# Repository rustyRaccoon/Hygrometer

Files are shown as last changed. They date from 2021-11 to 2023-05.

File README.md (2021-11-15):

# Hygrometer
Hygrometer based on DHT11 and four 7-segment displays

DHT library took way too much space so I had to code the communication directly.
As of v4.0 this works quite nicely.

I got the power consumption down to 0.1 mA/h:
<1 mA in sleep mode (my lab power supply doesn't show any current draw)
~6 mA when updating measurements (currently 2 measurements aka 8 seconds every 5 minutes)
~68 mA when displaying measurements (currently for 5 seconds)

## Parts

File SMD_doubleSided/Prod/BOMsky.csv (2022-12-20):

Id | Designator | Package | Quantity | Designation | Supplier and ref
1 | R2,R3,R5,R6,R7,R8,R9,R10,R11,R12,R13,R14,R15,R16,R17,R4 | R_1206_3216Metric_Pad1.30x1.75mm_HandSolder | 16 | 270
2 | U2,U3 | SOIC-16_3.9x9.9mm_P1.27mm | 2 | 74HC595
3 | J1 | PinHeader_1x02_P2.54mm_Vertical | 1 | POWER
4 | R1,R19,R18,R20 | R_1206_3216Metric_Pad1.30x1.75mm_HandSolder | 4 | 10k
5 | SW1 | PinHeader_1x02_P2.54mm_Vertical | 1 | WAKE UP
6 | J6 | PinHeader_1x04_P2.54mm_Vertical | 1 | DHT11
7 | Q1,Q2 | SOT-23_Handsoldering | 2 | NPN_CBE
8 | C4 | CP_EIA-3216-18_Kemet-A_Pad1.58x1.35mm_HandSolder | 1 | 4.7u
9 | C2,C3,C1 | CP_EIA-3216-18_Kemet-A_Pad1.58x1.35mm_HandSolder | 3 | 100n
10 | U1 | FakeSMD_DIP-8 | 1 | ATtiny45V-10P
11 | U4,U5 | HDSP-523Y | 2 | HDSP-523Y

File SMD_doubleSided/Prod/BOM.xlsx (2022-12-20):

Designator | Package | Quantity | Designation | Sourced | Order number
R2,R3,R5,R6,R7,R8,R9,R10,R11,R12,R13,R14,R15,R16,R17,R4 | R_1206_3216Metric_Pad1.30x1.75mm_HandSolder | 16 | R270 | YES | NA
U2,U3 | SOIC-16_3.9x9.9mm_P1.27mm | 2 | 74HC595 | YES | NA
J1 | PinHeader_1x02_P2.54mm_Vertical | 1 | POWER | YES | NA
R1,R19,R18,R20 | R_1206_3216Metric_Pad1.30x1.75mm_HandSolder | 4 | 10k | YES | NA
SW1 | PinHeader_1x02_P2.54mm_Vertical | 1 | WAKE UP | YES | NA
J6 | PinHeader_1x04_P2.54mm_Vertical | 1 | DHT11 | YES | NA
Q1,Q2 | SOT-23_Handsoldering | 2 | NPN_CBE | YES | NA
C4 | CP_EIA-3216-18_Kemet-A_Pad1.58x1.35mm_HandSolder | 1 | 4.7u | YES | NA
C2,C3,C1 | CP_EIA-3216-18_Kemet-A_Pad1.58x1.35mm_HandSolder | 3 | 100n | YES | NA
U1 | FakeSMD_DIP-8 | 1 | ATtiny45V-10P | YES | NA
U4,U5 | HDSP-523Y | 2 | HDSP-523Y | YES | NA

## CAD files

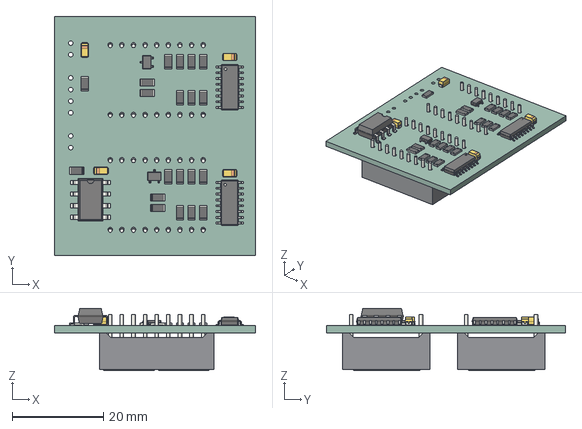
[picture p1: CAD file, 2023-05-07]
SMD_doubleSided/Hygrometer_SMD_doubleSided.step
43.9 x 52.3 x 13.6 mm
PCB

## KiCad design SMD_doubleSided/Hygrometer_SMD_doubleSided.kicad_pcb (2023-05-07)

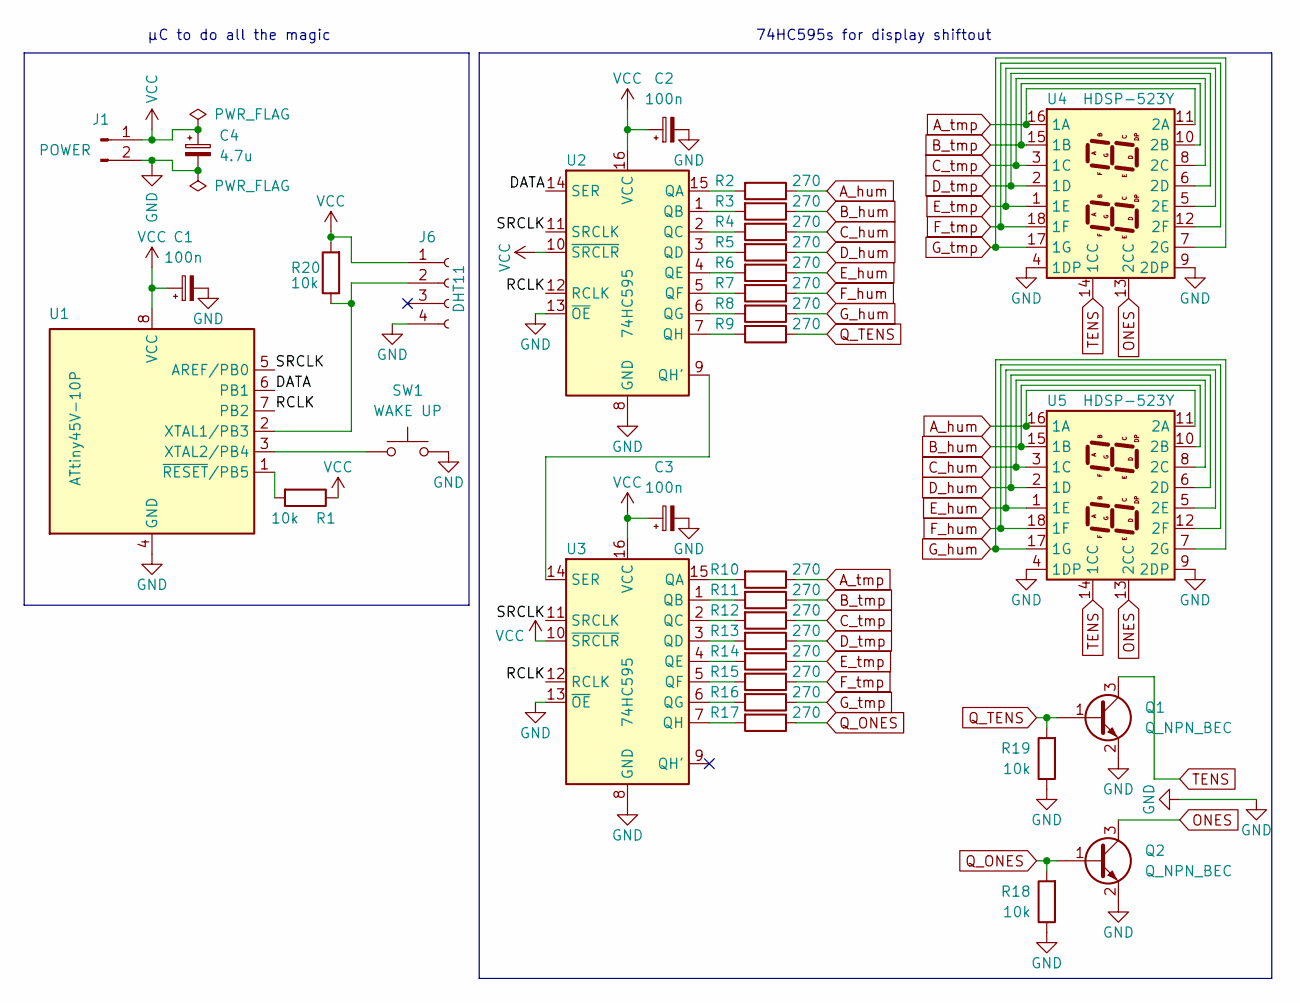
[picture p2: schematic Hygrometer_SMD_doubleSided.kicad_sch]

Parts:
C1, C2, C3: 100n; CP_EIA-3216-18_Kemet-A_Pad1.58x1.35mm_HandSolder
C4: 4.7u; CP_EIA-3216-18_Kemet-A_Pad1.58x1.35mm_HandSolder
J1: POWER; PinHeader_1x02_P2.54mm_Vertical
J6: DHT11; PinHeader_1x04_P2.54mm_Vertical
Q1, Q2: Q_NPN_BEC; SOT-23W
R1, R18, R19, R20: 10k; R_1206_3216Metric_Pad1.30x1.75mm_HandSolder
R2, R3, R4, R5, R6, R7, R8, R9, R10, R11, R12, R13, R14, R15, R16, R17: 270; R_1206_3216Metric_Pad1.30x1.75mm_HandSolder
SW1: WAKE UP; PinHeader_1x02_P2.54mm_Vertical
U1: ATtiny45V-10P; FakeSMD_DIP-8
U2, U3: 74HC595; SOIC-16_3.9x9.9mm_P1.27mm
U4, U5: HDSP-523Y

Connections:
/DATA: U1.6 (PB1), U2.14 (SER)
/RCLK: U1.7 (PB2), U2.12 (RCLK), U3.12 (RCLK)
/SRCLK: U1.5 (AREF/PB0), U2.11 (SRCLK), U3.11 (SRCLK)
A_hum: R2.1, U5.11 (2A), U5.16 (1A)
A_tmp: R10.1, U4.11 (2A), U4.16 (1A)
B_hum: R3.1, U5.10 (2B), U5.15 (1B)
B_tmp: R11.1, U4.10 (2B), U4.15 (1B)
C_hum: R4.1, U5.3 (1C), U5.8 (2C)
C_tmp: R12.1, U4.3 (1C), U4.8 (2C)
D_hum: R5.1, U5.2 (1D), U5.6 (2D)
D_tmp: R13.1, U4.2 (1D), U4.6 (2D)
E_hum: R6.1, U5.1 (1E), U5.5 (2E)
E_tmp: R14.1, U4.1 (1E), U4.5 (2E)
F_hum: R7.1, U5.12 (2F), U5.18 (1F)
F_tmp: R15.1, U4.12 (2F), U4.18 (1F)
GND: C1.2, C2.2, C3.2, C4.2, J1.2, J6.4, Q1.2 (E), Q2.2 (E), R18.1, R19.1, SW1.2, U1.4 (GND), U2.8 (GND), U2.13 (~OE), U3.8 (GND), U3.13 (~OE), U4.4 (1DP), U4.9 (2DP), U5.4 (1DP), U5.9 (2DP)
G_hum: R8.1, U5.7 (2G), U5.17 (1G)
G_tmp: R16.1, U4.7 (2G), U4.17 (1G)
unnamed: J6.2, R20.1, U1.2 (XTAL1/PB3)
unnamed: R1.2, U1.1 (~RESET/PB5)
unnamed: R2.2, U2.15 (QA)
unnamed: R3.2, U2.1 (QB)
unnamed: R4.2, U2.2 (QC)
unnamed: R5.2, U2.3 (QD)
unnamed: R6.2, U2.4 (QE)
unnamed: R7.2, U2.5 (QF)
unnamed: R8.2, U2.6 (QG)
unnamed: R9.2, U2.7 (QH)
unnamed: R10.2, U3.15 (QA)
unnamed: R11.2, U3.1 (QB)
unnamed: R12.2, U3.2 (QC)
unnamed: R13.2, U3.3 (QD)
unnamed: R14.2, U3.4 (QE)
unnamed: R15.2, U3.5 (QF)
unnamed: R16.2, U3.6 (QG)
unnamed: R17.2, U3.7 (QH)
unnamed: SW1.1, U1.3 (XTAL2/PB4)
unnamed: U2.9 (QH'), U3.14 (SER)
ONES: Q2.3 (C), U4.13 (2CC), U5.13 (2CC)
Q_ONES: Q2.1 (B), R17.1, R18.2
Q_TENS: Q1.1 (B), R9.1, R19.2
TENS: Q1.3 (C), U4.14 (1CC), U5.14 (1CC)
VCC: C1.1, C2.1, C3.1, C4.1, J1.1, J6.1, R1.1, R20.2, U1.8 (VCC), U2.10 (~SRCLR), U2.16 (VCC), U3.10 (~SRCLR), U3.16 (VCC)

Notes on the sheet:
74HC595s for display shiftout
µC to do all the magic

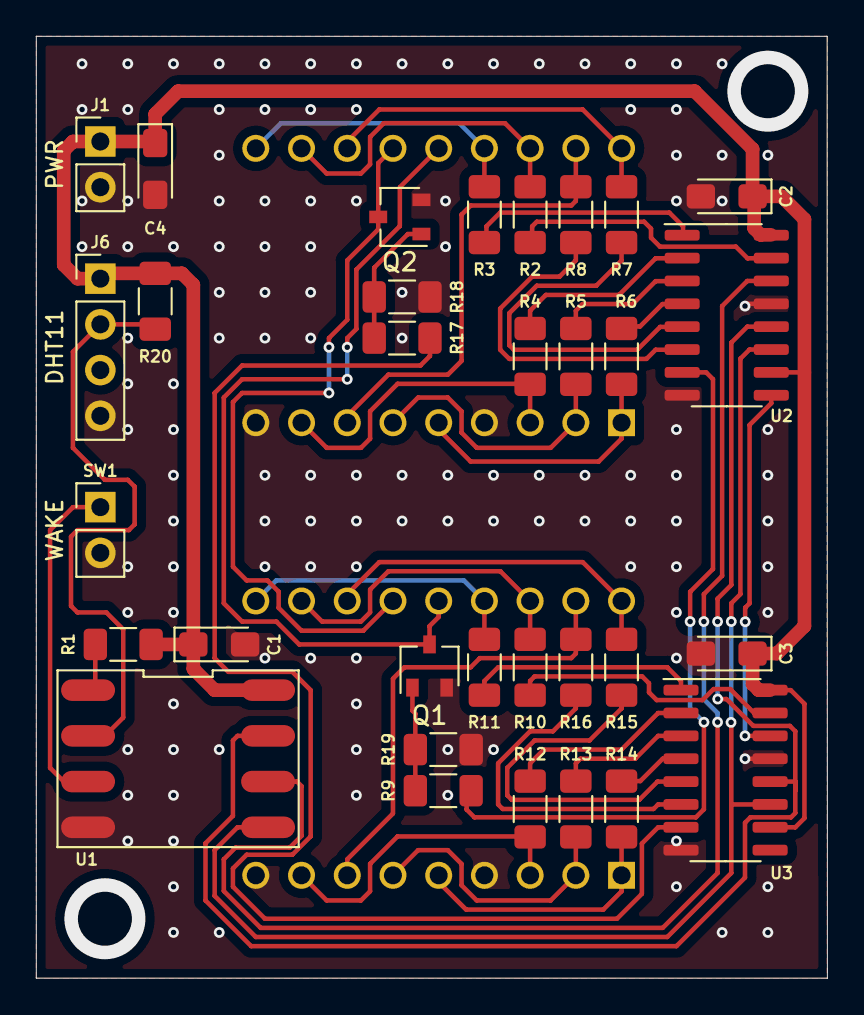
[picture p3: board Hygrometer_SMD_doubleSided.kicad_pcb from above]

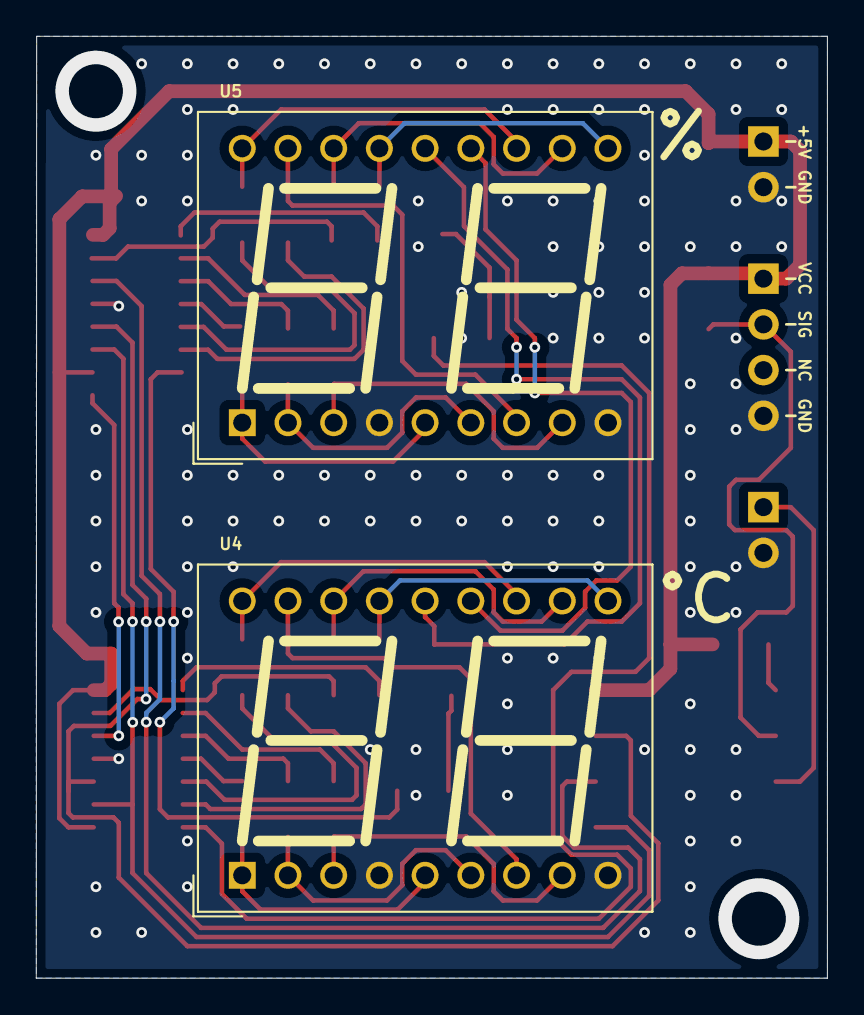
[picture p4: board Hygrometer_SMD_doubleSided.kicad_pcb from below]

Board: 2 copper layers, 43.9 x 52.3 mm, 34 parts (2 on the bottom side), 43 nets.

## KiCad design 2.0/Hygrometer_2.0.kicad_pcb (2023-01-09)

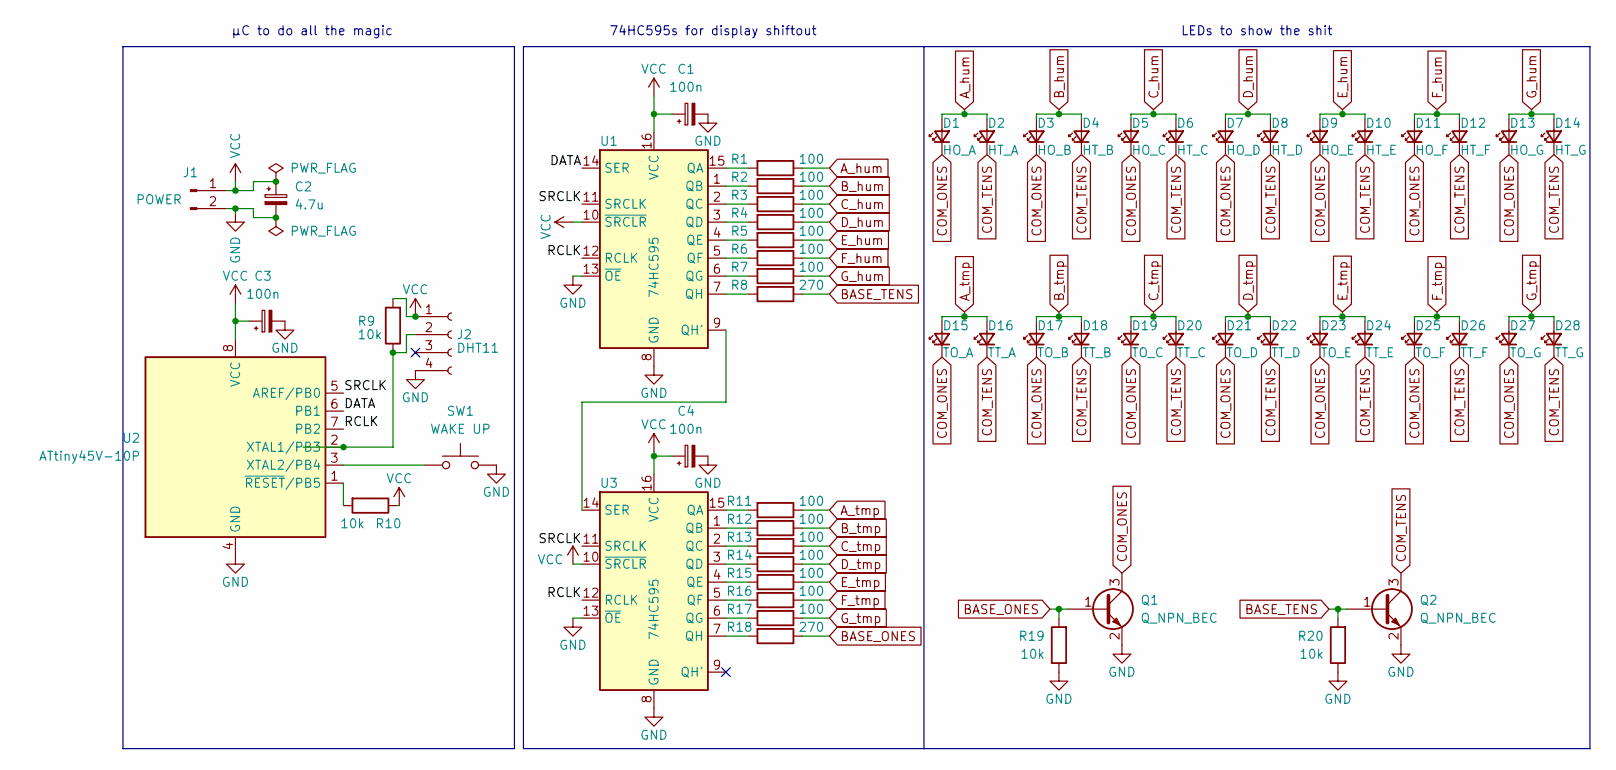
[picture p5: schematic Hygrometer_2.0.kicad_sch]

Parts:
C1, C3, C4: 100n; CP_EIA-3216-18_Kemet-A
C2: 4.7u; CP_EIA-3216-18_Kemet-A
D1: HO_A; LED_D3.0mm
D2: HT_A; LED_D3.0mm
D3: HO_B; LED_D3.0mm
D4: HT_B; LED_D3.0mm
D5: HO_C; LED_D3.0mm
D6: HT_C; LED_D3.0mm
D7: HO_D; LED_D3.0mm
D8: HT_D; LED_D3.0mm
D9: HO_E; LED_D3.0mm
D10: HT_E; LED_D3.0mm
D11: HO_F; LED_D3.0mm
D12: HT_F; LED_D3.0mm
D13: HO_G; LED_D3.0mm
D14: HT_G; LED_D3.0mm
D15: TO_A; LED_D3.0mm
D16: TT_A; LED_D3.0mm
D17: TO_B; LED_D3.0mm
D18: TT_B; LED_D3.0mm
D19: TO_C; LED_D3.0mm
D20: TT_C; LED_D3.0mm
D21: TO_D; LED_D3.0mm
D22: TT_D; LED_D3.0mm
D23: TO_E; LED_D3.0mm
D24: TT_E; LED_D3.0mm
D25: TO_F; LED_D3.0mm
D26: TT_F; LED_D3.0mm
D27: TO_G; LED_D3.0mm
D28: TT_G; LED_D3.0mm
J1: POWER; PinHeader_1x02_P2.54mm_Vertical
J2: DHT11; PinHeader_1x04_P2.54mm_Vertical
Q1, Q2: Q_NPN_BEC; SOT-23
R1, R2, R3, R4, R5, R6, R7, R11, R12, R13, R14, R15, R16, R17: 100; R_1206_3216Metric_Pad1.30x1.75mm_HandSolder
R8, R18: 270; R_1206_3216Metric_Pad1.30x1.75mm_HandSolder
R9, R10, R19, R20: 10k; R_1206_3216Metric_Pad1.30x1.75mm_HandSolder
SW1: WAKE UP; PinHeader_1x02_P2.54mm_Vertical
U1, U3: 74HC595; FakeSMD_DIP-16
U2: ATtiny45V-10P; FakeSMD_DIP-8

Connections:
/DATA: U1.14 (SER), U2.6 (PB1)
/RCLK: U1.12 (RCLK), U2.7 (PB2), U3.12 (RCLK)
/SRCLK: U1.11 (SRCLK), U2.5 (AREF/PB0), U3.11 (SRCLK)
A_hum: D1.2 (A), D2.2 (A), R1.1
A_tmp: D15.2 (A), D16.2 (A), R11.1
BASE_ONES: Q1.1 (B), R18.1, R19.2
BASE_TENS: Q2.1 (B), R8.1, R20.2
B_hum: D3.2 (A), D4.2 (A), R2.1
B_tmp: D17.2 (A), D18.2 (A), R12.1
COM_ONES: D1.1 (K), D3.1 (K), D5.1 (K), D7.1 (K), D9.1 (K), D11.1 (K), D13.1 (K), D15.1 (K), D17.1 (K), D19.1 (K), D21.1 (K), D23.1 (K), D25.1 (K), D27.1 (K), Q1.3 (C)
COM_TENS: D2.1 (K), D4.1 (K), D6.1 (K), D8.1 (K), D10.1 (K), D12.1 (K), D14.1 (K), D16.1 (K), D18.1 (K), D20.1 (K), D22.1 (K), D24.1 (K), D26.1 (K), D28.1 (K), Q2.3 (C)
C_hum: D5.2 (A), D6.2 (A), R3.1
C_tmp: D19.2 (A), D20.2 (A), R13.1
D_hum: D7.2 (A), D8.2 (A), R4.1
D_tmp: D21.2 (A), D22.2 (A), R14.1
E_hum: D9.2 (A), D10.2 (A), R5.1
E_tmp: D23.2 (A), D24.2 (A), R15.1
F_hum: D11.2 (A), D12.2 (A), R6.1
F_tmp: D25.2 (A), D26.2 (A), R16.1
GND: C1.2, C2.2, C3.2, C4.2, J1.2, J2.4, Q1.2 (E), Q2.2 (E), R19.1, R20.1, SW1.2, U1.8 (GND), U1.13 (~OE), U2.4 (GND), U3.8 (GND), U3.13 (~OE)
G_hum: D13.2 (A), D14.2 (A), R7.1
G_tmp: D27.2 (A), D28.2 (A), R17.1
unnamed: J2.2, R9.1, U2.2 (XTAL1/PB3)
unnamed: R1.2, U1.15 (QA)
unnamed: R2.2, U1.1 (QB)
unnamed: R3.2, U1.2 (QC)
unnamed: R4.2, U1.3 (QD)
unnamed: R5.2, U1.4 (QE)
unnamed: R6.2, U1.5 (QF)
unnamed: R7.2, U1.6 (QG)
unnamed: R8.2, U1.7 (QH)
unnamed: R10.2, U2.1 (~RESET/PB5)
unnamed: R11.2, U3.15 (QA)
unnamed: R12.2, U3.1 (QB)
unnamed: R13.2, U3.2 (QC)
unnamed: R14.2, U3.3 (QD)
unnamed: R15.2, U3.4 (QE)
unnamed: R16.2, U3.5 (QF)
unnamed: R17.2, U3.6 (QG)
unnamed: R18.2, U3.7 (QH)
unnamed: SW1.1, U2.3 (XTAL2/PB4)
unnamed: U1.9 (QH'), U3.14 (SER)
VCC: C1.1, C2.1, C3.1, C4.1, J1.1, J2.1, R9.2, R10.1, U1.10 (~SRCLR), U1.16 (VCC), U2.8 (VCC), U3.10 (~SRCLR), U3.16 (VCC)

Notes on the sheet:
74HC595s for display shiftout
LEDs to show the shit
µC to do all the magic

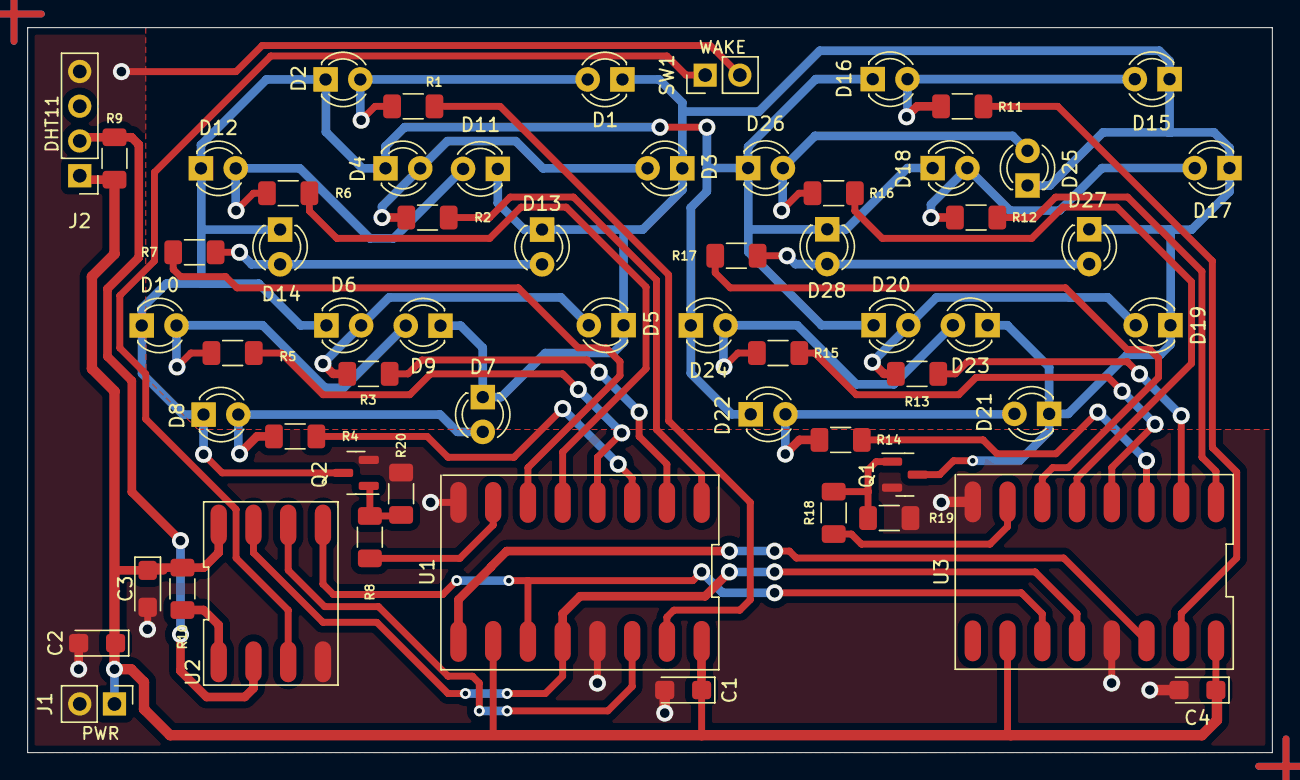
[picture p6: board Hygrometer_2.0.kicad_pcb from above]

Board: 2 copper layers, 91.0 x 53.0 mm, 60 parts (0 on the bottom side), 43 nets.

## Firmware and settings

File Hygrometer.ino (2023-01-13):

/*
  Humidity/Temperature sensor setup with DHT-11
  Two digits for humidity
  Two digits for temperature
  Button to wake up from sleep
  NPNs activated via 8th bit in 74HC595s, always alternating
  
  !! Needs to be set up with 8 MHz internal clock AND bootloader apparently !!
  
  In the first version (1.0) one of the 3-pin headers is turned around, switching the TENS_GND and ONES_GND!!
  This needs to be corrected in updateDisplay() when setting the NPN bits

Digits are
tens  NPN_on | g | f | e | d | c | b | a
ones  NPN_on | g | f | e | d | c | b | a

  Author:   rustyRaccoon
  Date:     2023-01-13
  Version:  6.0
*/

#include <avr/sleep.h>  //sleep Modes
#include <avr/power.h>  //power management
#include <avr/wdt.h>    //doggy stuff

//define attiny pins
#define CLK PB0
#define DATA PB1
#define LATCH PB2
#define SENSOR PB3
#define INT_PIN PB4

//define other stuffU
#define LED_DELAY 5

//fixed variables
uint8_t ignoreButton;         //time to ignore button presses for
const byte numLookup[] = {    //array lookup for number display; ascending order: 0, 1, 2, ...
  0b01111110, //0
  0b00110000, //1
  0b01101101, //2
  0b01111001, //3
  0b00110011, //4
  0b01011011, //5
  0b01011111, //6
  0b01110000, //7
  0b01111111, //8
  0b01111011  //9
};

// changing variables
short ones_data;            //16-bits for display of ones
short tens_data;            //16-bits for display of tens
byte sevSeg;                //7-segment bit pattern
byte measurements;          //number of measurements taken
byte sleepCounter;          //sleep cycles since last measurement
byte humI;                  //integral part of humidity measurement
byte humD;                  //decimal part of humidity measurement (we'll throw this away but it's returned so we need to put it somewhere)
byte tempI;                 //integral part of temperature measurement
byte tempD;                 //decimal part of temperature measurement (we'll throw this away but it's returned so we need to put it somewhere)
bool firstPair;             //tracks which pair of 7-segments is on
bool btnPress;              //tracks if button is pressed
bool readTriggered;         //tracks if a reading was requested
bool awakeTime;             //tracks if sleeping is allowed
uint32_t lastAcquisition;   //tracks the last acquisition time
uint32_t sleepTimer;        //tracks the wakeup time
uint32_t buttonPressTime;   //tracks when the button was last pressed
uint32_t onTime;            //tracks the time one pair of digits should be on

void setup() {
  resetWatchdog(); //do this first in case WDT fires
  cli(); //disable interrupts during setup

  pinMode(INT_PIN, INPUT_PULLUP); //set interrupt pin as input w/ internal pullup
  pinMode(DATA, OUTPUT);          //set serial data as output
  pinMode(CLK, OUTPUT);           //set shift register clock as output
  pinMode(LATCH, OUTPUT);         //set output register (latch) clock as output
  pinMode(SENSOR, INPUT);         //set DHT11 pin as input

  // Interrupts
  PCMSK = bit(INT_PIN); //enable interrupt handler (ISR)
  GIFR  |= bit(PCIF);   //clear any outstanding interrupts
  GIMSK |= bit(PCIE);   //enable PCINT interrupt in the general interrupt mask

  //default conditions
  /*
  bit 0-6: temperature segments
  bit 7: NPN for single digits
  bit 8-14: humidity segments
  bit 15: NPN for tens digits
  */
  tens_data = 0b0000000000000000;
  ones_data = 0b0000000000000000;
  measurements = 0;
  sleepCounter = 0;
  firstPair = true;
  btnPress = false;
  awakeTime = false;
  readTriggered = false;
  lastAcquisition = 0;
  sleepTimer = 0;
  onTime = 0;
  humI = 0;
  humD = 0;
  tempI = 0;
  tempD = 0;
  buttonPressTime = 0;
  ignoreButton = 50;

  digitalWrite(LATCH, 0);         //set latch pin LOW so nothing gets shifted out
  shiftOut(DATA, CLK, tens_data); //shift out LED states for 7-segments of tens
  digitalWrite(LATCH, 1);         //sent everything out in parallel

  delay(2000);      //wait for DHT to be ready
  updateDisplay();  //read DHT11 once in the beginning

  lastAcquisition = millis();
  while((millis()-lastAcquisition) >= 3000){
    //shift out the next batch of data to the display
    digitalWrite(LATCH, 0); //set latch pin LOW so nothing gets shifted out

    if (firstPair) {
      shiftOut(DATA, CLK, 0b0110000101100000); //shift out LED states for 7-segments of tens
      firstPair = false;              //reset first digit flag
    }
    else {
      shiftOut(DATA, CLK, 0b0010111000011111); //shift out LED states for 7-segments of ones
      firstPair = true;               //set first digit flag
    }

    digitalWrite(LATCH, 1); //sent everything out in parallel
    delay(LED_DELAY); //wait for some time until switching to the other displays    
  }
  
  sei(); //enable interrupts after setup
}

void loop() {
  //if 5 minutes are not over yet, increase counter and sleep again; button press overrules this
  if (sleepCounter <= 38 && !btnPress) {
    sleepCounter++;
    goToSleep();
  }
  else {
    awakeTime = true; //keep awake until action is done
    
    //need to wait two seconds until sensor is ready (I think; maybe next time I'll try without this but now I'm pressed for time)
    if (!readTriggered && (millis() - lastAcquisition) > 2000) {
      readTriggered = true;
      lastAcquisition = millis();
    }
    else if (readTriggered && (millis() - lastAcquisition) > 2000) { //slow sensor, so readings may be up to 2 seconds old
      updateDisplay();

      readTriggered = false;
      measurements++;
      lastAcquisition = millis();
    }

    if (btnPress) {
      // if((millis()-onTime)>=LED_DELAY){
      //   onTime = millis(); //update timestamp
        
        //shift out the next batch of data to the display
        digitalWrite(LATCH, 0); //set latch pin LOW so nothing gets shifted out

        if (firstPair) {
          shiftOut(DATA, CLK, tens_data); //shift out LED states for 7-segments of tens
          firstPair = false;              //reset first digit flag
        }
        else {
          shiftOut(DATA, CLK, ones_data); //shift out LED states for 7-segments of ones
          firstPair = true;               //set first digit flag
        }

        digitalWrite(LATCH, 1); //sent everything out in parallel
        delay(LED_DELAY); //wait for some time until switching to the other displays
        
        //sleep after 5s display time
        if ((millis() - sleepTimer) > 5000) { 
          sleepCounter = 0;
          awakeTime = false;
          goToSleep();
        }
      // }
    }
    else {
      //we want to acquire at least one measurement so I'm explicitly checking that
      if (measurements >= 2) {
        sleepCounter = 0;
        awakeTime = false;
        goToSleep();
      }
    }
  }
}

void start_signal(byte SENSOR_PIN) {
  pinMode(SENSOR_PIN, OUTPUT);        //set pin as output
  digitalWrite(SENSOR_PIN, LOW);      //set pin LOW
  delay(18);                          //wait 18 ms
  digitalWrite(SENSOR_PIN, HIGH);     //set pin HIGH
  pinMode(SENSOR_PIN, INPUT_PULLUP);  //set pin as input and pull to VCC (10k)
}

boolean read_dht11(byte SENSOR_PIN) {
  uint16_t rawHumidity = 0;
  uint16_t rawTemperature = 0;
  uint16_t data = 0;
  uint8_t checkSum = 0;
  unsigned long startTime;

  for (int8_t i = -3; i < 80; i++) {  //loop 80 iterations, representing 40 bits * 2 (HIGH + LOW)
    byte high_time;                   //stores the HIGH time of the signal
    startTime = micros();             //stores the time the data transfer started

    /*
    sensor should pull line LOW and keep for 80µs (while SENSOR_PIN == HIGH)
    then pull HIGH and keep for 80µs (while SENSOR_PIN == LOW)
    then pull LOW again, aka send data (while SENSOR_PIN == HIGH)
    */
    do {                                                  //waits for sensor to respond
      high_time = (unsigned long)(micros() - startTime);  //update HIGH time
      if (high_time > 90) {                               //times out after 90 microseconds
        //Serial.println("ERROR_TIMEOUT");
        return false;
      }
    }
    while (digitalRead(SENSOR_PIN) == (i & 1) ? HIGH : LOW);

    //actual data starts at iteration 0
    if (i >= 0 && (i & 1)) {  //if counter is odd, do this (only counts t_on time and ignores t_off)
      data <<= 1;             //left shift data stream by 1 since we are at a the next bit

      //t_on of bit 0 is maximum 30µs and of bit 1 is at least 68µs
      if (high_time > 30) {
        data |= 1; //we got a one
      }
    }

    switch ( i ) {
      case 31:                  //bit 0-16 is humidity
        rawHumidity = data;
        break;
      case 63:                  //bit 17-32 is temperature
        rawTemperature = data;
      case 79:                  //bit 33-40 is checksum
        checkSum = data;
        data = 0;
        break;
    }
  }

  //humidity
  humI = rawHumidity >> 8;
  rawHumidity = rawHumidity << 8;
  humD = rawHumidity >> 8;

  //temperature
  tempI = rawTemperature >> 8;
  rawTemperature = rawTemperature << 8;
  tempD = rawTemperature >> 8;

  if ((byte)checkSum == (byte)(tempI + tempD + humI + humD)) {
    return true;
  }
  else {
    return false;
  }
}

void updateDisplay(){
  //cli(); //disable all interrupts for the duration of the read since the communication is rather timing-sensitive
  start_signal(SENSOR); //send start sequence

  if (read_dht11(SENSOR)) {    
    // update tens bit string
    tens_data = 0b0000000000000000;     //reset to all 0s
    tens_data |= numLookup[humI / 10];  //bitwise OR the result with the output short
    tens_data = tens_data << 8;         //shift by 8 so it's almost in the right place (see below)
    tens_data |= numLookup[tempI / 10]; //bitwise OR the result with the output short
    tens_data = tens_data << 1;         //shift by 1 so everything is in the right place
    tens_data |= 0b0000000100000000;    //set NPN for tens pair to active and ones NPN to inactive

    // update ones bit string
    ones_data = 0b0000000000000000;     //reset to all 0s
    ones_data |= numLookup[humI % 10];  //bitwise OR the result with the output short
    ones_data = ones_data << 8;         //shift by 8 so it's almost in the right place (see below)
    ones_data |= numLookup[tempI % 10]; //bitwise OR the result with the output short
    ones_data = ones_data << 1;         //shift by 1 so everything is in the right place
    ones_data |= 0b0000000000000001;    //set NPN for ones pair to active and tens NPN to inactive
  }
  else {
    tens_data = 0b1001111110011110;
    ones_data = 0b0000101000001011;
  }
  
  //sei(); //enable all interrupts again since communication with sensor is over
}

void goToSleep() {
  //turn off 7-segments and NPNs
  digitalWrite(LATCH, 0);
  shiftOut(DATA, CLK, 0b0000000000000000);
  digitalWrite(LATCH, 1);

  set_sleep_mode (SLEEP_MODE_PWR_DOWN); //set deep sleep mode
  ADCSRA = 0;                           //turn off ADC
  power_all_disable ();                 //power off ADC, Timer 0 and 1, serial interface
  cli();                                //timed sequence coming up, so disable interrupts
  btnPress = false;                     //reset button flag
  measurements = 0;                     //reset measurement counter
  resetWatchdog ();                     //get watchdog ready
  sleep_enable ();                      //ready to sleep
  sei();                                //interrupts are required now
  sleep_cpu ();                         //sleep
  sleep_disable ();                     //precaution
  power_all_enable ();                  //power everything back on
}

ISR(PCINT0_vect) {
  if(millis()-buttonPressTime >= ignoreButton){
    buttonPressTime = millis();
    btnPress = true;
    awakeTime = true;
    sleepTimer = millis();
  }
}

//watchdog interrupt
ISR(WDT_vect) {
  wdt_disable(); //disable watchdog
}

void resetWatchdog() {
  MCUSR = 0;                                    //clear various "reset" flags
  WDTCR = bit (WDCE) | bit (WDE) | bit (WDIF);  //allow changes, disable reset, clear existing interrupt
  WDTCR = bit (WDIE) | bit (WDP3) | bit (WDP0); //set WDIE, and 8 seconds delay
  wdt_reset();
}

//shifts 16 bits out LSB first, on the rising edge of the clock.
void shiftOut(int dataPin, int clockPin, short toBeSent) {
  int i = 0;
  int pinState = 0;

  //clear everything out just in case
  digitalWrite(dataPin, 0);
  digitalWrite(clockPin, 0);

  //loop through bits in the data bytes
  for (i = 0; i <= 15; i++) {
    digitalWrite(clockPin, 0);
    //if the value AND a bitmask result is true then set pinState to 1
    if (toBeSent & (1 << i)) {
      pinState = 1;
    }
    else {
      pinState = 0;
    }

    digitalWrite(dataPin, pinState);  //sets the pin to HIGH or LOW depending on pinState
    digitalWrite(clockPin, 1);        //shifts bits on upstroke of clock pin
    digitalWrite(dataPin, 0);         //zero the data pin after shift to prevent bleed through
  }
  digitalWrite(clockPin, 0);          //stop shifting
}

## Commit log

2021-11-09 Replaced DHT11 library with custom code
    The library was too memory-heavy so I had to write something of my own, based on this: "https://www.engineersgarage.com/articles-arduino-dht11-humidity-temperature-sensor-interfacing/"
    [Hygrometer.ino]
2021-11-12 Updated major issues
    ~ Signals for NPNs were flipped
    ~ Reduced timer between displays from 50 to 5 ms to reduce flicker
    ~ Added reset of displays to setup()
    ~ Replaced 2s delay for sensor with conditional 2s wait so the rest of the loop() runs and keeps updating the display (otherwise it gets stuck on one number)
    [Hygrometer.ino]
2021-11-15 Fix/reduction of power consumption
    The high current draw was due to a faulty 74HC595N chip. I replaced it and now it's down to 6mA when the display is off and 67 mA when the display is on. I also reduced the periodic measurements from 3 to 2 to increase sleep time.
    [Hygrometer.ino]
2021-11-15 Updated sleep timer period to 5 minutes
2022-12-19 Update Hygrometer.ino
    + Disabled interrupts during sensor read since it fucks with the communication
    + Added time to ignore button to prevent bouncing (could be done waaaay fancier)
    ~ Formatted variables nicer
    [Hygrometer.ino]
2022-12-20 Restructured files a bit
    [BOM.xlsx, BOMsky.csv, Hygrometer.kicad_pcb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]
2022-12-30 Added button lines
    [Hygrometer_2.0.kicad_pcb]
2023-01-09 Updated resistors for LEDs
    [Hygrometer_2.0.kicad_pcb, Hygrometer_2.0.kicad_sch]
2023-01-12 Changed bits for NPNs and added comment to explain
    In essence, there's an error on the 1.0 version PCB that switched the connections for TENS_GND and ONES_GND, necessitating a switch of the two. Since this is corrected in subsequent PCB versions, it needs to be switched back.
    [Hygrometer.ino]
2023-01-13 Some bugfixes and improvements
    Changed LED on time counter from 'delay()' to if statement with millis() comparison
    Changed Error display order of digits to correct one
    Renamed variable for acquisition time tracking
    Moved interrupt turning on and off in sensor acquisition to outside of if/else
    [Hygrometer.ino]
2023-01-31 Deleted obsolete files
    [Hygrometer.kicad_pcb, Hygrometer.sch]
2023-03-25 Updated files
    [Hygrometer_SMD_doubleSided.kicad_pcb, Hygrometer_SMD_doubleSided.step]
2023-05-07 Deleted backups; changed silkscreen location
    [Hygrometer_SMD_doubleSided.kicad_pcb, Hygrometer_SMD_doubleSided.step]
